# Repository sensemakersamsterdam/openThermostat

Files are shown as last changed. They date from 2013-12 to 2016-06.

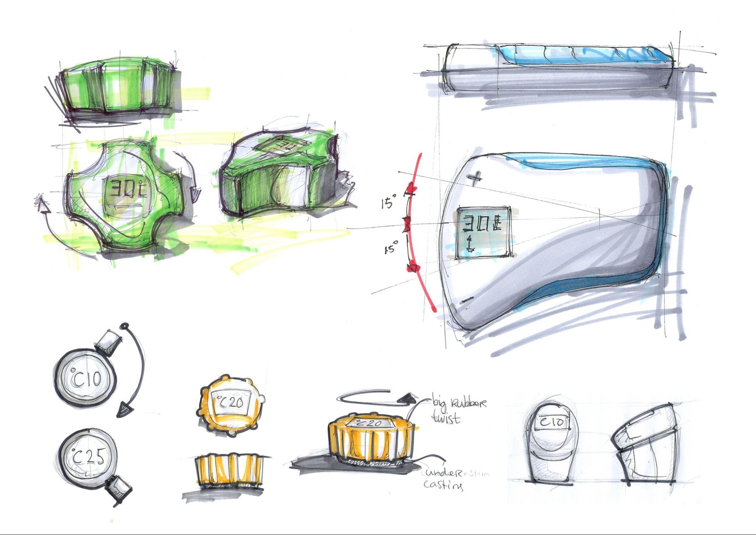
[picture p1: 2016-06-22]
case/openThermostat-case-Design-options.jpg

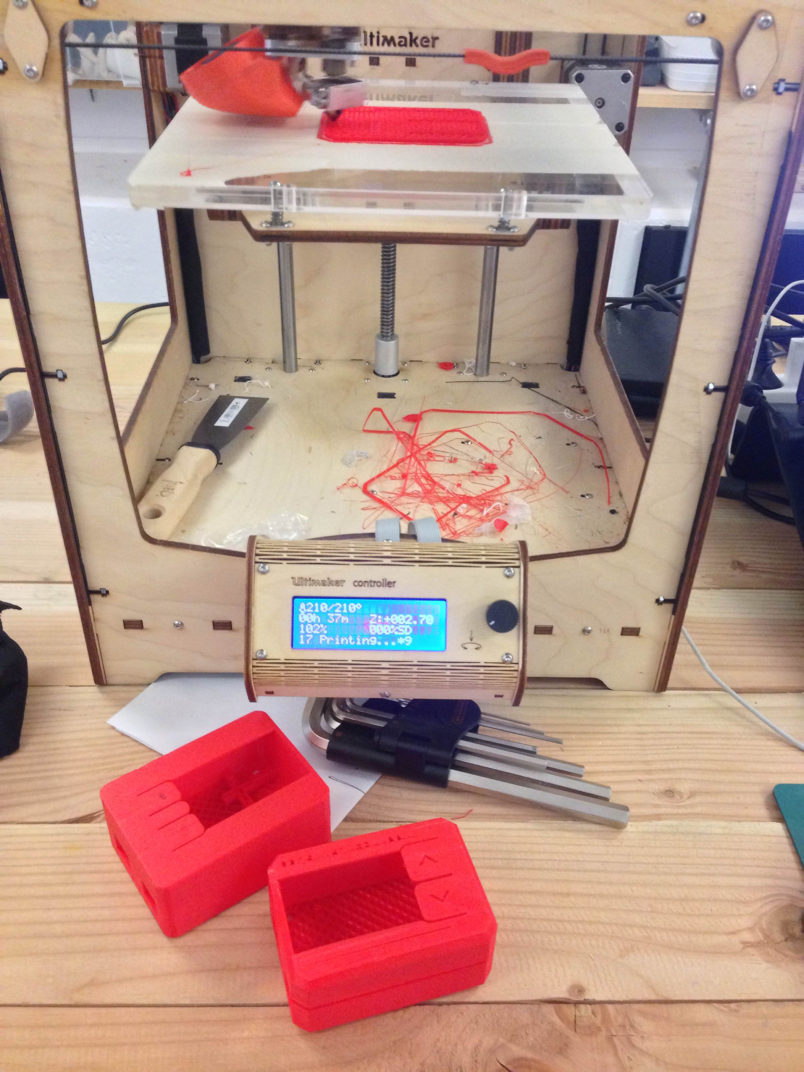
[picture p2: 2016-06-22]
case/openThermostat-Case-Prototype2-Printing.jpg

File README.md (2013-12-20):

# openThermostat
openThermostat is an Open (source) Thermostat design consisting of both hardware and software which offers basic functionality that can be used as a base for every Maker or DIYer to expand upon.

The current version is implemented as an Arduino shield.

# Getting started
To get started you can either [download everything](https://github.com/sensemakersamsterdam/openThermostat/archive/master.zip) in this repository or clone it with `git clone https://github.com/sensemakersamsterdam/openThermostat.git`.
Additionally to get the wiki documentation run `git submodule init` and `git submodule update`.

The repository contains the following files/folders:
* firmware: Arduino sketch to compile and upload to the Arduino the shield is mounted on
  * display_test: Documented code to test the display
  * temp_test: Documented code to test the DS18B20 temperature sensor
* PCB: EAGLE Schematic and PCB layout files as well as exports to PDF and DXF
  * pictures: PNG pictures from the PCB layout and schematic
* wiki: the contents of the openThermostat wiki repository.

More details about building an openThermostatShield and about using the Arduino sketches can be found on the [openThermostatShield wiki page](../../wiki/openThermostatShield).

# Contributing
If you want to contribute feel free to fork the repository, add your changes and send us a pull request. We'd be happy to accept your contributions.
Make your changes in a new branch and please include documentation (using the wiki) for new features and major changes in the pull request.

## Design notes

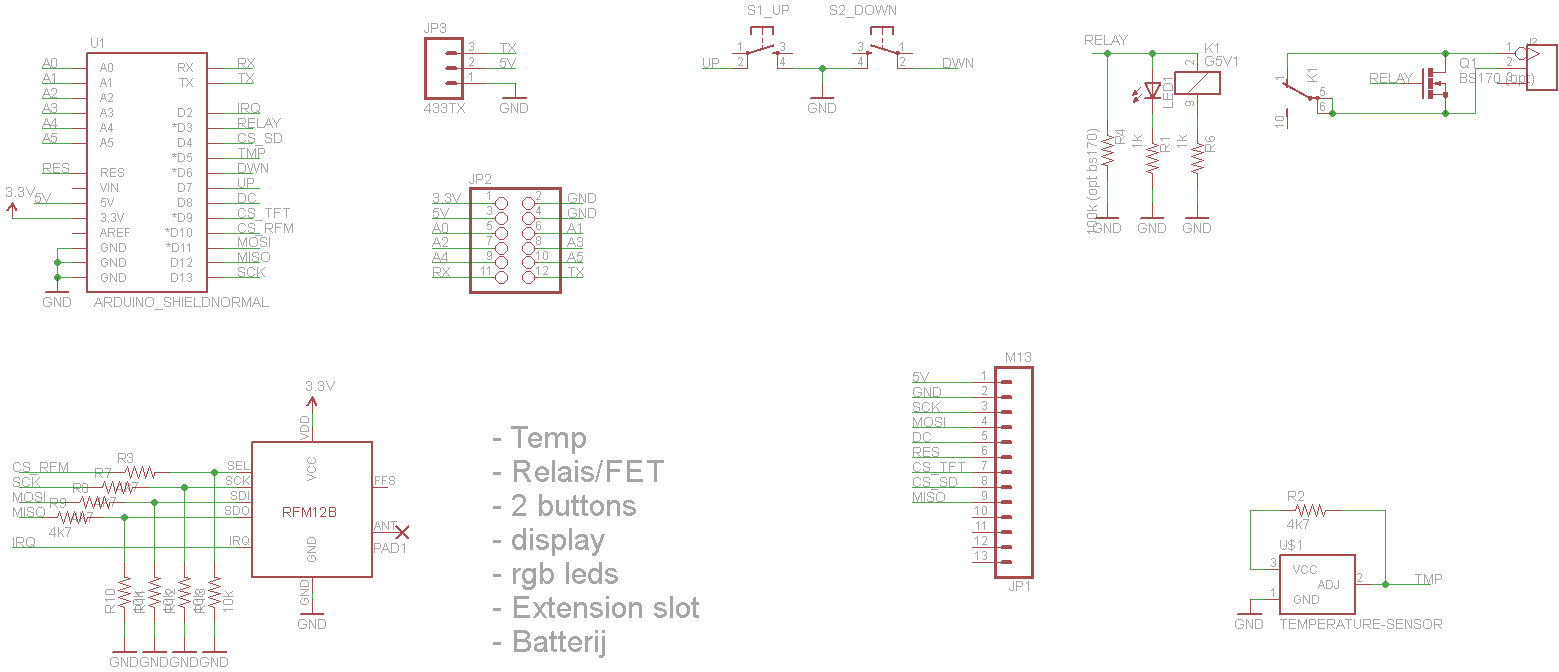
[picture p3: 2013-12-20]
PCB/pictures/openThermostatShield-schematic.png

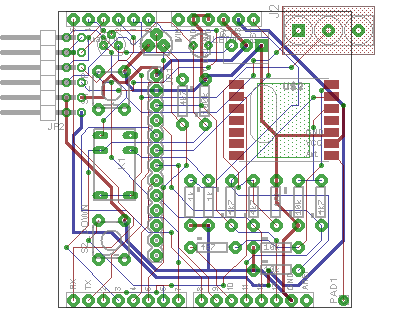
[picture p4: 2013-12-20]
PCB/pictures/openThermostatShield-PCB5.png

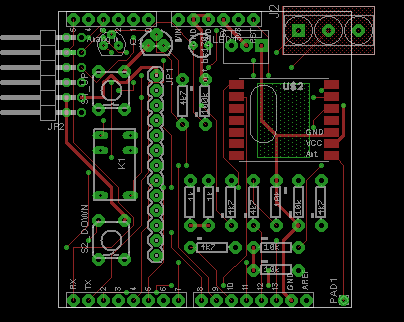
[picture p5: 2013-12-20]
PCB/pictures/openThermostatShield-PCB3.png

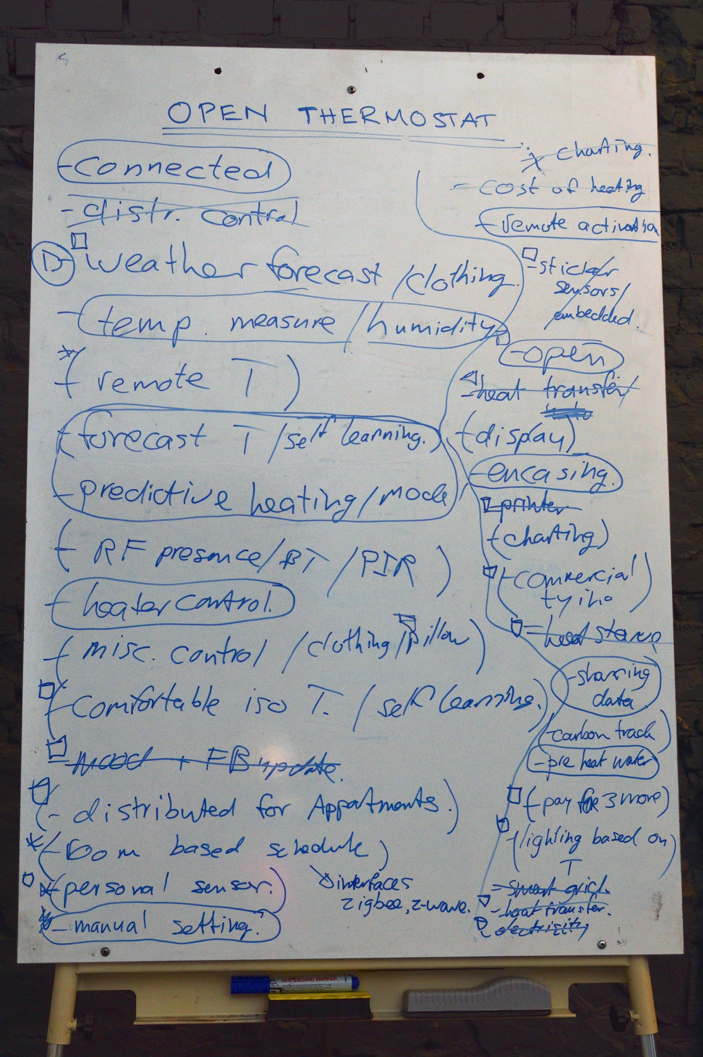
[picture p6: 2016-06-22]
doc/brainstorm.jpg

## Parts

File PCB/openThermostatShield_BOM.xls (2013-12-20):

 | Value | Device |  | Package | Parts | Description
1 |  | LED-3MM-NO_SILK | Stock | LED3MM-NS | LED1 | LEDs
1 |  | PINHD-2X6/90 | - | 2X06/90 | JP2 | PIN HEADER
1 |  | SCREW-TERMINAL-3P'5.08' | B | 3P-5.08 | J2
2 |  | TAC_SWITCHPTH | B | TACTILE-PTH | S1_UP
1 | 100k (opt bs170) | RESISTORAXIAL-0.3 | - | AXIAL-0.3 | R4 | Resistor
4 | 10k | RESISTORAXIAL-0.3 | B | AXIAL-0.3 | R10
2 | 1k | RESISTORAXIAL-0.3 | Stock | AXIAL-0.3 | R1
1 | 433TX | M03POLAR | - | MOLEX-1X3 | JP3 | Header 3
5 | 4k7 | RESISTORAXIAL-0.3 | B | AXIAL-0.3 | R2
1 | ARDUINO_SHIELDNORMAL | ARDUINO_SHIELDNORMAL | B | DUEMILANOVE_SHIELD_5X5 | U1 | Arduino shield footprint
1 | BS170 (opt) | BS170 | - | SOT54E | Q1 | N-CHANNEL MOS FET
1 | G5V1 | G5V1 | B | G5V1 | K1 | RELAY
1 | M13 | M13 | B | 1X13 | JP1 | 13-pin single row .1 header"
1 | RFM12B | RFM12B | Stock | RFM12B | U$2
1 | TEMPERATURE-SENSOR | TEMPERATURE-SENSOR | Stock | TO-92 | U$1 | TO-92 temp sensor

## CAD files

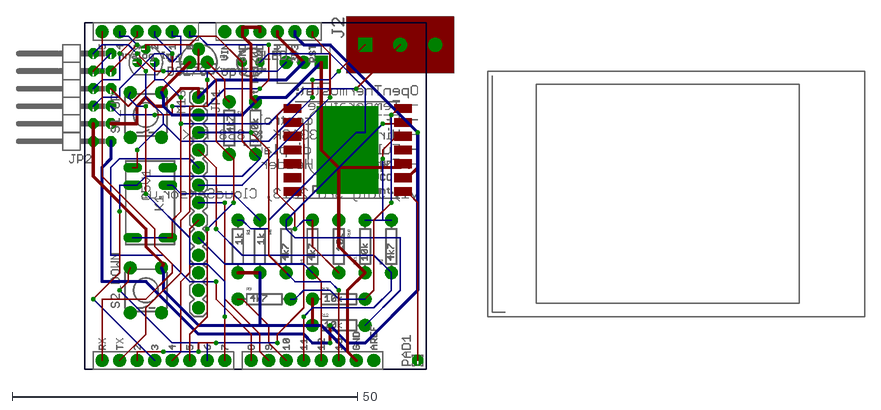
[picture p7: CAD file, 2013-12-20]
PCB/openThermostatShield.dxf
122.9 x 51.2

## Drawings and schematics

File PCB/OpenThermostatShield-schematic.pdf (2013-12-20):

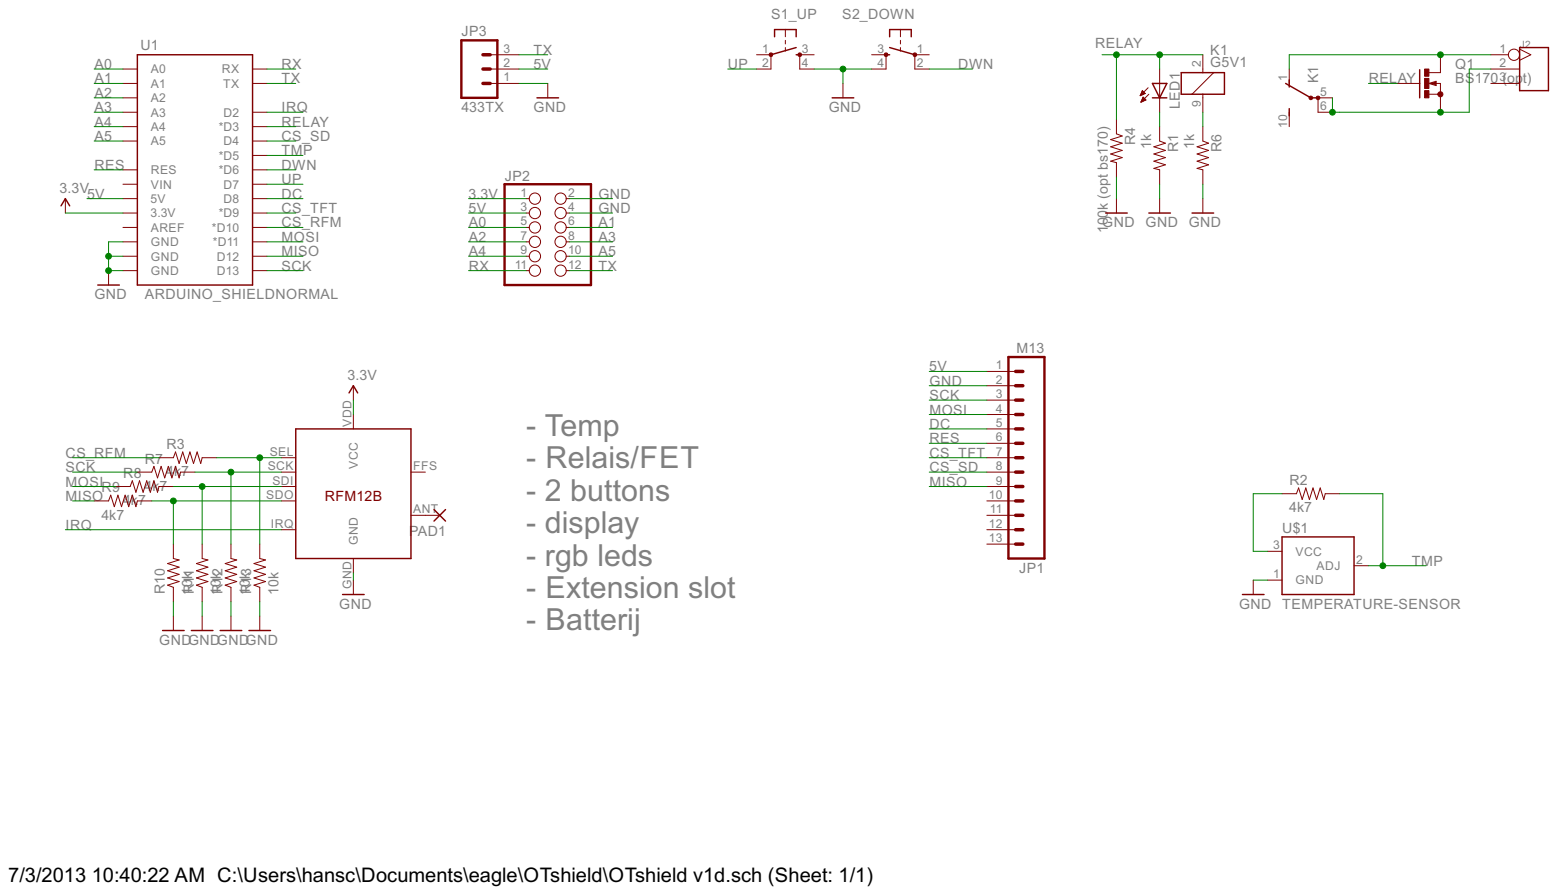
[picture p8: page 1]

SDI SDO

IRQ

7/3/2013 10:40:22 AM C:\Users\hansc\Documents\eagle\OTshield\OTshield v1d.sch (Sheet: 1/1)

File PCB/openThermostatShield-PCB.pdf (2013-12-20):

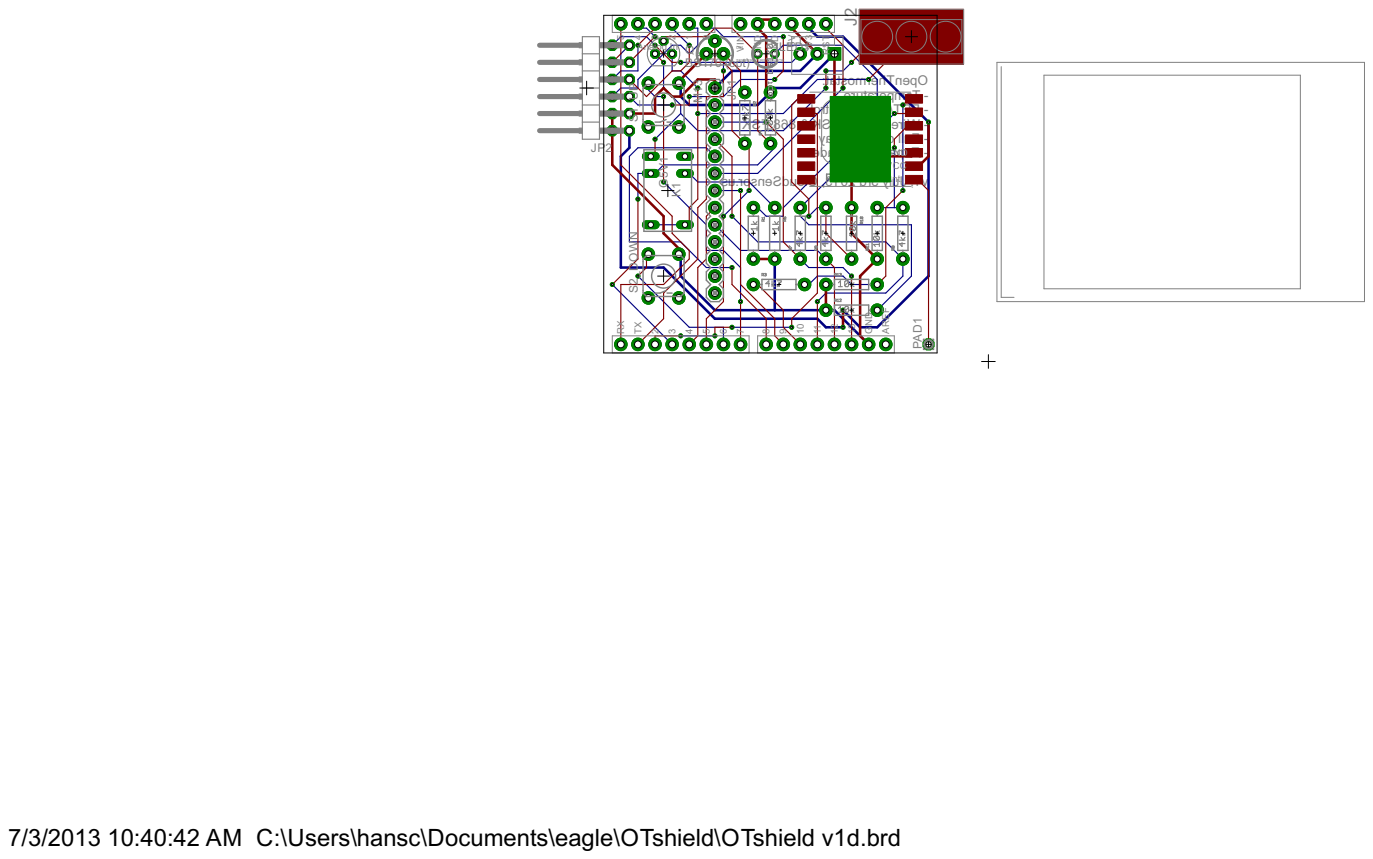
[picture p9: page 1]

7/3/2013 10:40:42 AM C:\Users\hansc\Documents\eagle\OTshield\OTshield v1d.brd

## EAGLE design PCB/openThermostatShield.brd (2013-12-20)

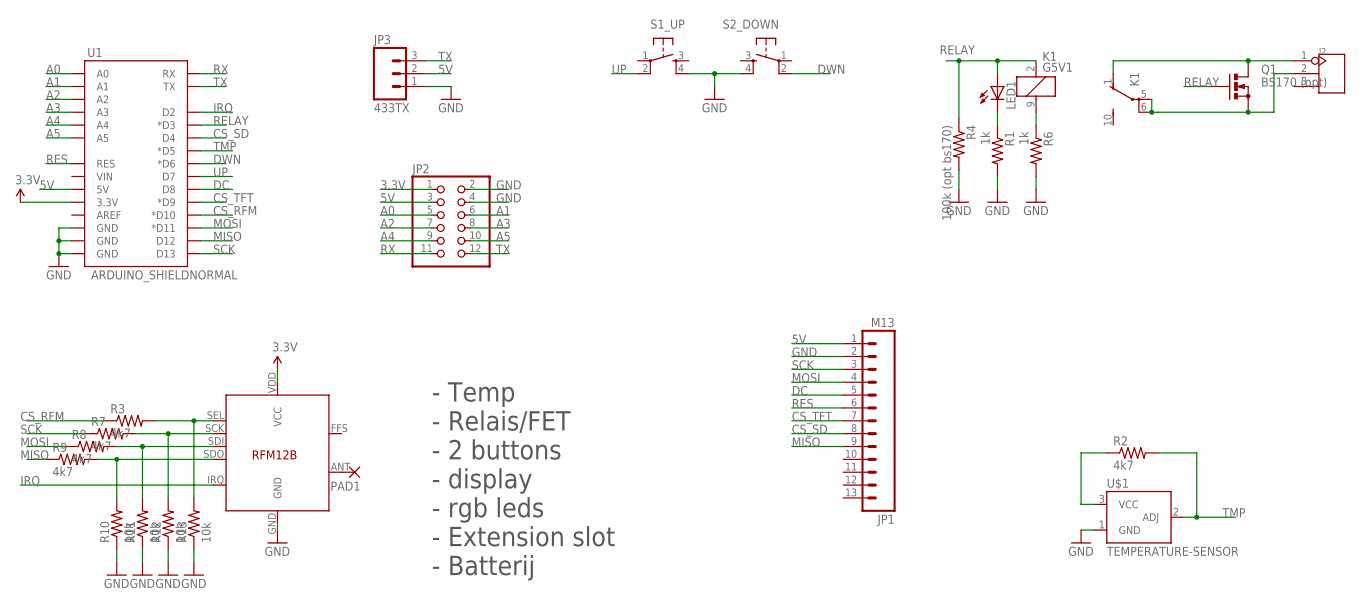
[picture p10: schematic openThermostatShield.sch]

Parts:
J2: SCREW-TERMINAL-3P'5.08'; 3P-5.08
JP1: M13; 1X13
JP2: PINHD-2X6/90; 2X06/90
JP3: 433TX; MOLEX-1X3
K1: G5V1
LED1: LED-3MM-NO_SILK; LED3MM-NS
PAD1: 1,6/0,8
Q1: BS170 (opt); SOT54E
R1, R6: 1k; AXIAL-0.3
R2, R3, R7, R8, R9: 4k7; AXIAL-0.3
R4: 100k (opt bs170); AXIAL-0.3
R10, R11, R12, R13: 10k; AXIAL-0.3
S1_UP, S2_DOWN: TAC_SWITCHPTH; TACTILE-PTH
U1: ARDUINO_SHIELDNORMAL; DUEMILANOVE_SHIELD_5X5
U$1: TEMPERATURE-SENSOR; TO-92
U$2: RFM12B

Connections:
3.3V: JP2.1, U1.3.3V, U$2.VDD (VCC)
5V: JP1.1, JP2.3, JP3.2, U1.5V
A0: JP2.5, U1.A0
A1: JP2.6, U1.A1
A2: JP2.7, U1.A2
A3: JP2.8, U1.A3
A4: JP2.9, U1.A4
A5: JP2.10, U1.A5
CS_RFM: R3.P$1 (1), U1.D10 (*D10)
CS_SD: JP1.8, U1.D4
CS_TFT: JP1.7, U1.D9 (*D9)
DC: JP1.5, U1.D8
DWN: S2_DOWN.2, U1.D6 (*D6)
GND: JP1.2, JP2.2, JP2.4, JP3.1, R1.P$2 (2), R4.P$2 (2), R6.P$2 (2), R10.P$1 (1), R11.P$1 (1), R12.P$1 (1), R13.P$1 (1), S1_UP.4, S2_DOWN.4, U1.GND@0 (GND), U1.GND@1 (GND), U1.GND@2 (GND), U$1.1 (GND), U$2.GND
IRQ: U1.D2, U$2.IRQ
MISO: JP1.9, R9.P$1 (1), U1.D12
MOSI: JP1.4, R8.P$1 (1), U1.D11 (*D11)
unnamed: K1.9 (2), R6.P$1 (1)
unnamed: J2.1, K1.1 (O), Q1.D
unnamed: LED1.K (C), R1.P$1 (1)
unnamed: J2.2, K1.5, K1.6, Q1.S
unnamed: R2.P$1 (1), U$1.3 (VCC)
unnamed: PAD1.1, U$2.ANT
unnamed: R9.P$2 (2), R10.P$2 (2), U$2.SDO
unnamed: R8.P$2 (2), R11.P$2 (2), U$2.SDI
unnamed: R7.P$2 (2), R12.P$2 (2), U$2.SCK
unnamed: R3.P$2 (2), R13.P$2 (2), U$2.SEL
RELAY: K1.2 (1), LED1.A, Q1.G, R4.P$1 (1), U1.D3 (*D3)
RES: JP1.6, U1.RES
RX: JP2.11, U1.RX
SCK: JP1.3, R7.P$1 (1), U1.D13
TMP: R2.P$2 (2), U1.D5 (*D5), U$1.2 (ADJ)
TX: JP2.12, JP3.3, U1.TX
UP: S1_UP.2, U1.D7

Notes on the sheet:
- Temp - Relais/FET - 2 buttons - display - rgb leds - Extension slot - Batterij

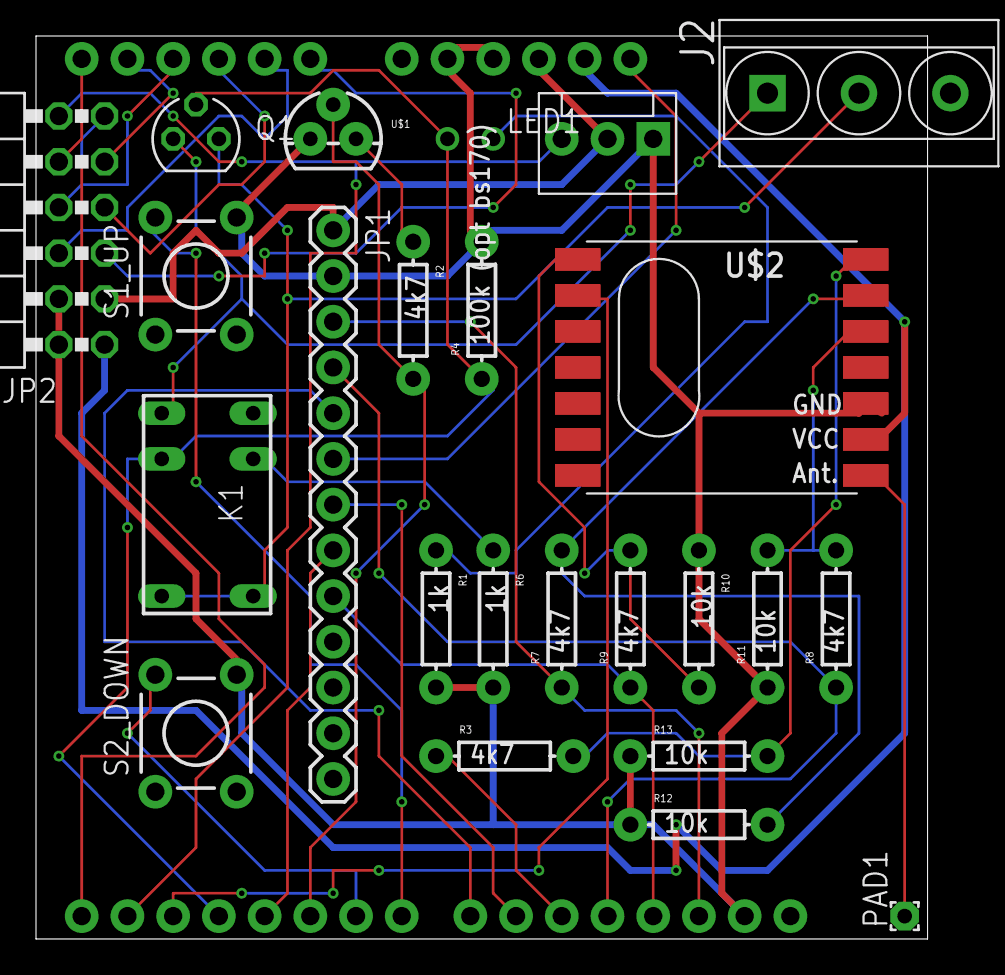
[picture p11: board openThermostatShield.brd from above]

Board: 2 copper layers, 49.5 x 50.2 mm, 25 parts (0 on the bottom side), 34 nets.

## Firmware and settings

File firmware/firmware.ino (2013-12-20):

// Open Thermostat software; written by Hans Crijns [cloudsensor.us]
//
// Graphincs based on: Adafruit_ST7735 > graphicstest_highspeed

#include <Adafruit_GFX.h>    // Core graphics library
#include <Adafruit_ST7735.h> // Hardware-specific library
#include <SPI.h>
#include <OneWire.h>
#include <DallasTemperature.h>

// tft display
#define cs       9
#define dc       8
#define rst      0  // Reset is hardcode; so used

#define tempPin  5  // temperature sensor DS18B20
#define upPin    6
#define downPin  7
#define heatPin  3  // Relay and LED

OneWire oneWire(tempPin);
DallasTemperature sensors(&oneWire);
DeviceAddress insideThermometer;

int change = 1;
int heat = 0;
float temp, oldtemp, settemp;
char buffer[10];
Adafruit_ST7735 tft = Adafruit_ST7735(cs, dc, rst);

void setup(void) {
  Serial.begin(9600);
  Serial.println("Open Thermostat v1\n");

  pinMode(upPin, INPUT);
  digitalWrite(upPin, HIGH);
  pinMode(downPin, INPUT);
  digitalWrite(downPin, HIGH);
  pinMode(heatPin, OUTPUT);

  tft.initR(INITR_BLACKTAB);   // initialize a ST7735S chip, black tab
  tft.fillScreen(ST7735_WHITE);
  tft.setRotation(1);
  
  sensors.begin();
  if (!sensors.getAddress(insideThermometer, 0)) 
    Serial.println("Unable to find address for Device 0"); 
  sensors.requestTemperatures();
  temp = sensors.getTempC(insideThermometer);
  settemp = temp;

  delay(1000);
}

void loop() {
  readTemp();
  
  if (!digitalRead(upPin)) {
    settemp += 0.5;
    change = 1;
    delay(200);
  }
  if (!digitalRead(downPin)) {
    settemp -= 0.5;
    change = 1;
    delay(200);
  }

  if(change) {
    updateDisplay();
    change = 0;
  }

  if (temp < settemp) {
    heat = 1;
    heater();
    heat = 0;
    change = 1;
  }

  delay(100);
}

void updateDisplay(void) {
  drawtext("Open Thermostat", 30, 10, ST7735_RED, 1);
  drawtext("Current:", 25, 30, ST7735_BLACK, 1);
  drawtext("Set:", 105, 30, ST7735_BLACK, 1);

  String tempStr = dtostrf(temp, 3, 1, buffer);
  tft.fillRoundRect(20, 40, 60, 40, 5, ST7735_BLUE);
  drawtext(tempStr, 25, 50, ST7735_WHITE, 2);
  
  String settempStr = dtostrf(settemp, 3, 1, buffer);
  tft.fillRoundRect(90, 40, 60, 40, 5, ST7735_WHITE);
  tft.drawRoundRect(90, 40, 60, 40, 5, ST7735_BLUE);
  drawtext(settempStr, 98, 50, ST7735_BLUE, 2);
}

void readTemp(void) {
  sensors.requestTemperatures();
  temp = sensors.getTempC(insideThermometer);
  //temp = DallasTemperature::toFahrenheit(temp);    // Uncomment for Fahrenheit
  if (temp != oldtemp) {
    change = 1;
    oldtemp = temp;
  }
  
  Serial.print("Current: ");
  Serial.print(temp);
  Serial.print("; Set: ");
  Serial.println(settemp);
}

void heater(void) {
  Serial.println("Heater on");
  digitalWrite(heatPin, HIGH);
  delay(3000);
  digitalWrite(heatPin, LOW);
  settemp = temp;
}

void drawtext(String text, int x, int y, int color, int large) {
  tft.setCursor(x, y);
  tft.setTextColor(color);
  tft.setTextWrap(true);
  tft.setTextSize(large);
  tft.print(text);
}

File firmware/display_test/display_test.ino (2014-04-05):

// Based on: Adafruit_ST7735 > graphicstest_highspeed
// And: http://www.instructables.com/id/Arduino-Watch-Build-Instructions/

#include <Arduino.h>        // To ensure this compiles on OS X with Arduino 1.0.5 IDE
#include <Adafruit_GFX.h>    // Core graphics library
#include <Adafruit_ST7735.h> // Hardware-specific library
#include <SPI.h>

//#define sclk 13
//#define mosi 11
#define cs   9
#define dc   8
#define rst  0  // you can also connect this to the Arduino reset

#define slow_color ST7735_BLUE
#define med_color ST7735_BLUE
#define fast_color ST7735_RED
#define plate_color ST7735_WHITE
#define border_color ST7735_BLACK

Adafruit_ST7735 tft = Adafruit_ST7735(cs, dc, rst);
float p = 3.1415926;
float sec = 0;
float usec = 0;
float minute = 0;
float uminute = 0;
float hour = 1;
float uhour = 0;

void setup(void) {
  Serial.begin(9600);
  Serial.print("ClockDemo CloudSensor v1");
  tft.initR(INITR_BLACKTAB);   // initialize a ST7735S chip, black tab
  tft.fillScreen(ST7735_WHITE);
  
  float clock_size = tft.width()/2.2;  //40.0;
  float x_clock = tft.width()/2;  //64.0; 
  float y_clock = tft.height()/2;  //64.0;
  
  tft.fillCircle(x_clock, y_clock, clock_size, border_color);
  tft.fillCircle(x_clock, y_clock, clock_size - 10, plate_color);
  
//  // large block of text
//  tft.fillScreen(ST7735_BLACK);
//  testdrawtext("Lorem ipsum dolor sit amet, consectetur adipiscing elit. Curabitur adipiscing ante sed nibh tincidunt feugiat. Maecenas enim massa, fringilla sed malesuada et, malesuada sit amet turpis. Sed porttitor neque ut ante pretium vitae malesuada nunc bibendum. Nullam aliquet ultrices massa eu hendrerit. Ut sed nisi lorem. In vestibulum purus a tortor imperdiet posuere. ", ST7735_WHITE);
//  delay(1000);
//
//  // tft print function!
//  tftPrintTest();
//  delay(4000);
}

void loop() {
  clockanalog(sec, usec, minute, uminute, hour, uhour);
  usec = sec; 
  sec++;
  if((int)sec%60 == 0) {
    uminute = minute;
    minute++;
    if((int)minute%60 == 0) {
      uhour = hour;
      hour++;
    }
  }
  delay(100);
  
}

void clockanalog(float sec, float usec, float minute, float uminute, float hour, float uhour) {
  
  float Pi = 3.14159;
  float clock_size = tft.width()/2.2;  //40.0;
  float x_clock = tft.width()/2;  //64.0; 
  float y_clock = tft.height()/2;  //64.0;
  
  tft.drawLine(x_clock, y_clock, x_clock + 0.6 * clock_size  * sin(Pi * (float(uminute)/60.0 + float(uhour))/6.0), y_clock - 0.6 * clock_size * cos(Pi * (float(uminute)/60.0 + float(uhour))/6.0), plate_color);
  tft.drawLine(x_clock, y_clock, x_clock + 0.8 * clock_size * sin(Pi * float(uminute)/30.0), y_clock - 0.8 * clock_size * cos(Pi * float(uminute)/30.0), plate_color);
  tft.drawLine(x_clock, y_clock, x_clock + 0.8 * clock_size * sin(Pi * float(usec)/30.0), y_clock - 0.8 * clock_size * cos(Pi * float(usec)/30.0), plate_color);
  tft.drawLine(x_clock, y_clock, x_clock + 0.6 * clock_size  * sin(Pi * (float(minute)/60.0 + float(hour))/6.0), y_clock - 0.6 * clock_size * cos(Pi * (float(minute)/60.0 + float(hour))/6.0), slow_color);
  tft.drawLine(x_clock, y_clock, x_clock + 0.8 * clock_size * sin(Pi * float(minute)/30.0), y_clock - 0.8 * clock_size * cos(Pi * float(minute)/30.0), med_color);
  tft.drawLine(x_clock, y_clock, x_clock + 0.8 * clock_size * sin(Pi * float(sec)/30.0), y_clock - 0.8 * clock_size * cos(Pi * float(sec)/30.0), fast_color);
  for(int i = 1; i < 13; i++)
  {
    tft.drawLine(x_clock + 0.9 * clock_size * sin(Pi * float(i)/6.0), y_clock - 0.9 * clock_size * cos(Pi * float(i)/6.0), x_clock + clock_size * sin(Pi * float(i)/6.0), y_clock - clock_size * cos(Pi * float(i)/6.0), plate_color);
  }
}

void testlines(uint16_t color) {
  tft.fillScreen(ST7735_BLACK);
  for (int16_t x=0; x < tft.width(); x+=6) {
    tft.drawLine(0, 0, x, tft.height()-1, color);
  }
  for (int16_t y=0; y < tft.height(); y+=6) {
    tft.drawLine(0, 0, tft.width()-1, y, color);
  }

  tft.fillScreen(ST7735_BLACK);
  for (int16_t x=0; x < tft.width(); x+=6) {
    tft.drawLine(tft.width()-1, 0, x, tft.height()-1, color);
  }
  for (int16_t y=0; y < tft.height(); y+=6) {
    tft.drawLine(tft.width()-1, 0, 0, y, color);
  }

  tft.fillScreen(ST7735_BLACK);
  for (int16_t x=0; x < tft.width(); x+=6) {
    tft.drawLine(0, tft.height()-1, x, 0, color);
  }
  for (int16_t y=0; y < tft.height(); y+=6) {
    tft.drawLine(0, tft.height()-1, tft.width()-1, y, color);
  }

  tft.fillScreen(ST7735_BLACK);
  for (int16_t x=0; x < tft.width(); x+=6) {
    tft.drawLine(tft.width()-1, tft.height()-1, x, 0, color);
  }
  for (int16_t y=0; y < tft.height(); y+=6) {
    tft.drawLine(tft.width()-1, tft.height()-1, 0, y, color);
  }
}

void testdrawtext(char *text, uint16_t color) {
  tft.setCursor(0, 0);
  tft.setTextColor(color);
  tft.setTextWrap(true);
  tft.print(text);
}

void testfastlines(uint16_t color1, uint16_t color2) {
  tft.fillScreen(ST7735_BLACK);
  for (int16_t y=0; y < tft.height(); y+=5) {
    tft.drawFastHLine(0, y, tft.width(), color1);
  }
  for (int16_t x=0; x < tft.width(); x+=5) {
    tft.drawFastVLine(x, 0, tft.height(), color2);
  }
}

void testdrawrects(uint16_t color) {
  tft.fillScreen(ST7735_BLACK);
  for (int16_t x=0; x < tft.width(); x+=6) {
    tft.drawRect(tft.width()/2 -x/2, tft.height()/2 -x/2 , x, x, color);
  }
}

void testfillrects(uint16_t color1, uint16_t color2) {
  tft.fillScreen(ST7735_BLACK);
  for (int16_t x=tft.width()-1; x > 6; x-=6) {
    tft.fillRect(tft.width()/2 -x/2, tft.height()/2 -x/2 , x, x, color1);
    tft.drawRect(tft.width()/2 -x/2, tft.height()/2 -x/2 , x, x, color2);
  }
}

void testfillcircles(uint8_t radius, uint16_t color) {
  for (int16_t x=radius; x < tft.width(); x+=radius*2) {
    for (int16_t y=radius; y < tft.height(); y+=radius*2) {
      tft.fillCircle(x, y, radius, color);
    }
  }
}

void testdrawcircles(uint8_t radius, uint16_t color) {
  for (int16_t x=0; x < tft.width()+radius; x+=radius*2) {
    for (int16_t y=0; y < tft.height()+radius; y+=radius*2) {
      tft.drawCircle(x, y, radius, color);
    }
  }
}

void testtriangles() {
  tft.fillScreen(ST7735_BLACK);
  int color = 0xF800;
  int t;
  int w = 63;
  int x = 159;
  int y = 0;
  int z = 127;
  for(t = 0 ; t <= 15; t+=1) {
    tft.drawTriangle(w, y, y, x, z, x, color);
    x-=4;
    y+=4;
    z-=4;
    color+=100;
  }
}

void testroundrects() {
  tft.fillScreen(ST7735_BLACK);
  int color = 100;
  int i;
  int t;
  for(t = 0 ; t <= 4; t+=1) {
    int x = 0;
    int y = 0;
    int w = 127;
    int h = 159;
    for(i = 0 ; i <= 24; i+=1) {
      tft.drawRoundRect(x, y, w, h, 5, color);
      x+=2;
      y+=3;
      w-=4;
      h-=6;
      color+=1100;
    }
    color+=100;
  }
}
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

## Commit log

2013-12-20 Add files from meetup/dropbox closes #2
    [openThermostatShield.brd, openThermostatShield.dxf, openThermostatShield.sch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]
2014-04-05 Update display_test.ino
    Added import for Arduino.h to ensure this compiles on OS X with Arduino 1.0.5 IDE
2014-04-05 Added a word document with details on how to solder the board and what other requirements are there in order to compile the test code.
2016-06-22 Add scenario's, brainstorm photo and case options and photo's

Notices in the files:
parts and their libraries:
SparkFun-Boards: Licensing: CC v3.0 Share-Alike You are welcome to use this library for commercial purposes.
